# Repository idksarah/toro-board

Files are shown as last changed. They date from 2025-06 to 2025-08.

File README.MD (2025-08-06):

# toro-board
fully custom gasket mount 60% hot swappable alice keyboard using a raspberry pi pico. <br>
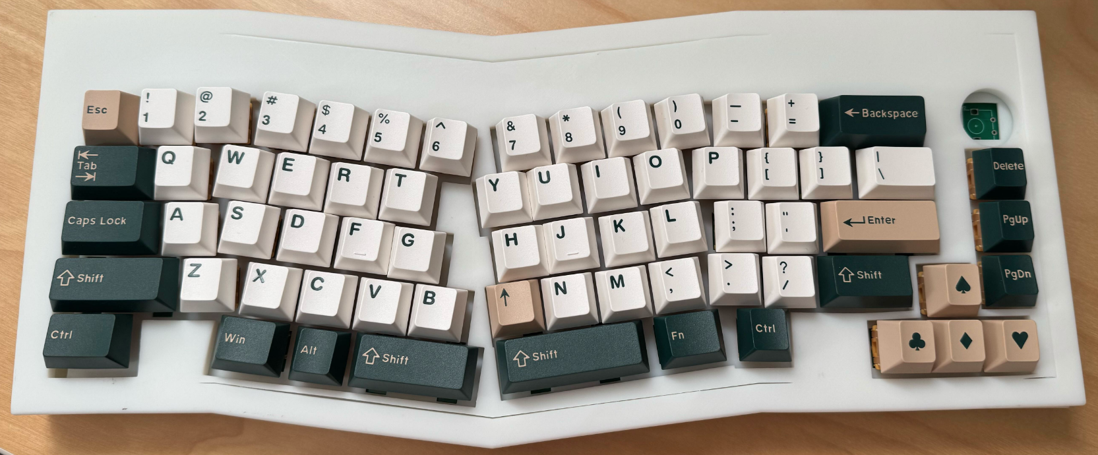
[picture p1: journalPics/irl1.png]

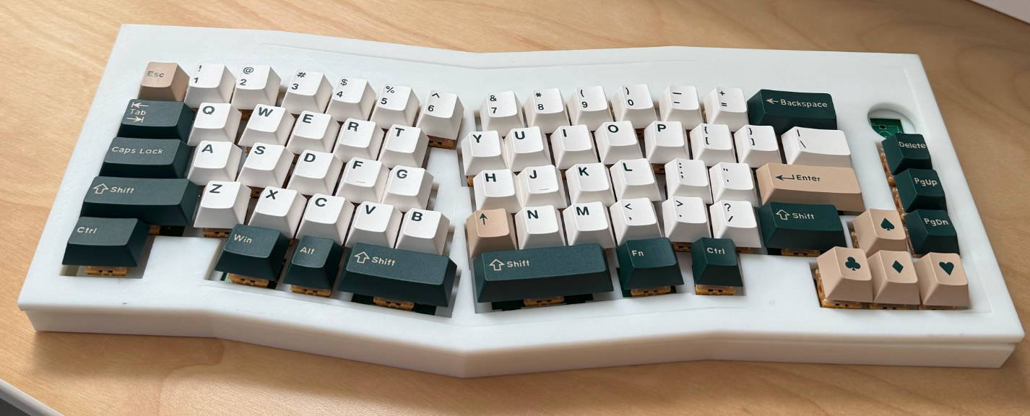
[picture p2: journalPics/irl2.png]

<br>
made this bc alice keyboards r cool but i've already spent too much on keyboards.
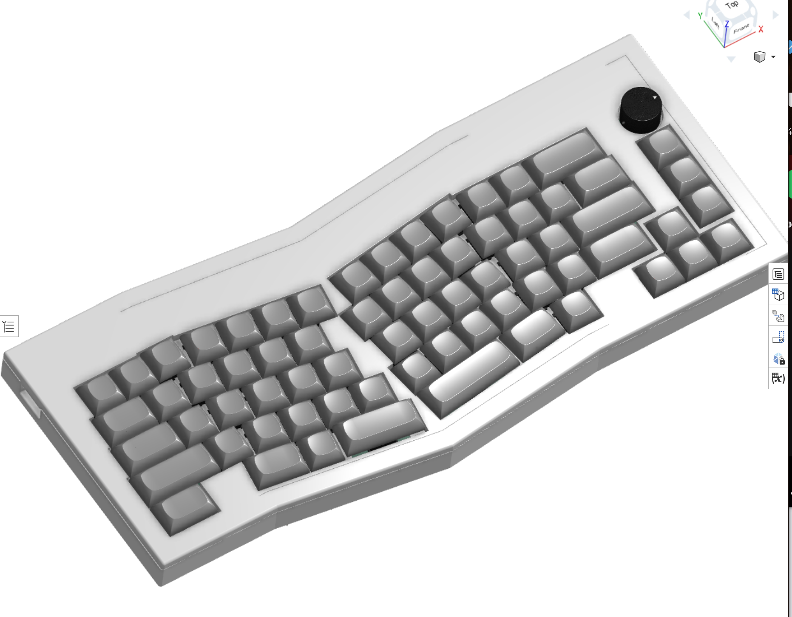
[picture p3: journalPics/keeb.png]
keeb

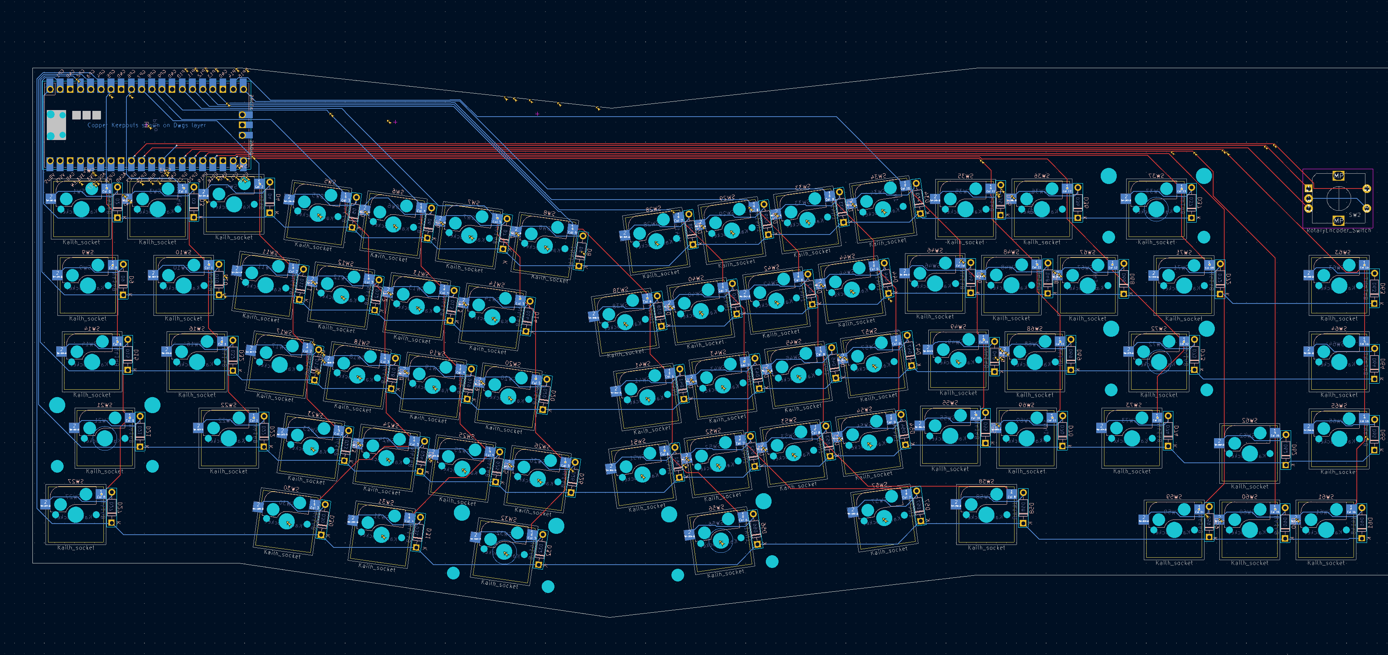
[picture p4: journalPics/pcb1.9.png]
pcb

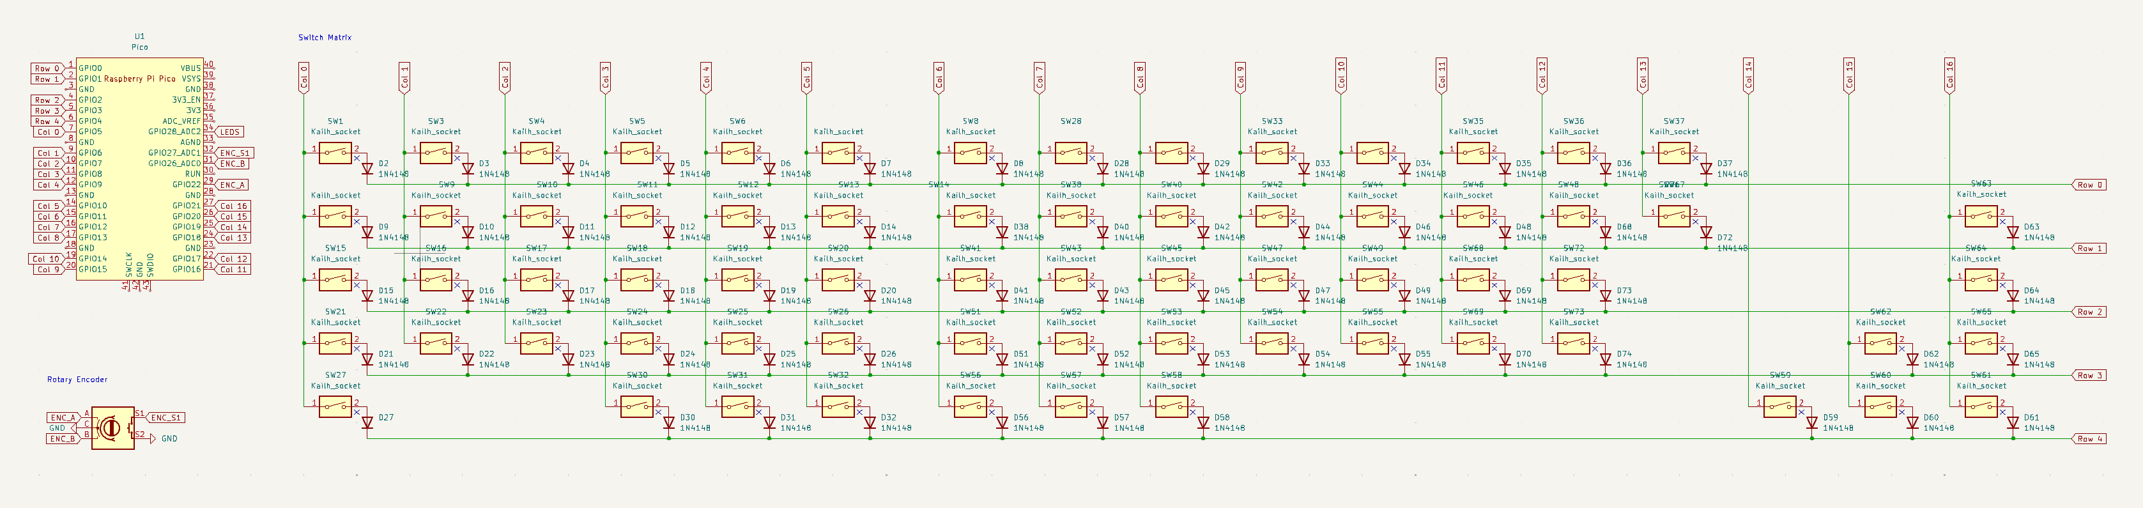
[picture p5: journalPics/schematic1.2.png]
idk


## firmware
qmk firmware

## bom

| item | quantity | price  | description | vendor | link |
|---|---|---|---|---|---|
| plate | 1 pc | 3.44 | 3d-printed acrylic plate | jlccnc | — |
| pcb | 5 pc | 21.60  | pcb | jlcpcb | — |
| case bottom | 1 pc | 28.34  | 3d-printed acrylic bottom case | jlccnc | — |
| case top | 1 pc | 9.35 | 3d-printed acrylic top case | jlccnc | — |
| [163 keys british racing green keyboard keycaps](https://www.aliexpress.us/item/3256807785511869.html) | 163 pc | 16.66  | keycaps | aliexpress | [link](https://www.aliexpress.us/item/3256807785511869.html) |
| [gateron ef curry switch 50g 5pin smd mx switch](https://www.aliexpress.us/item/3256805933064484.html) | 70 pc | 26.69 | ef curry switches | aliexpress | [link](https://www.aliexpress.us/item/3256805933064484.html) |
| [coiled keyboard cable type c to usb-a](https://www.aliexpress.us/item/3256808312113111.html) | 1 pc | 7.00 | usb c to usb a cable | aliexpress | [link](https://www.aliexpress.us/item/3256808312113111.html) |
| [70pcs kailh hot-swappable pcb socket hot plug](https://www.aliexpress.us/item/3256807039037559.html) | 70 pc | 3.73 | kailh hot swap sockets | aliexpress | [link](https://www.aliexpress.us/item/3256807039037559.html) |
| [15pcs gasket cotton strip](https://www.aliexpress.us/item/3256804985438216.html) | 15 pc | 3.74 | gasket for gasket mount  | aliexpress | [link](https://www.aliexpress.us/item/3256804985438216.html) |
| [switch puller tool](https://www.aliexpress.us/item/3256808571143767.html) | — | 3.92 | switch puller | aliexpress | [link](https://www.aliexpress.us/item/3256808571143767.html) |
| shipping (jlcpcb) | — | 20.00  | | jlcpcb | — |

---

### subtotals

- **jlcpcb total**: 21.60 (pcb) + 20.00 (shipping) → **$41.60**
- **aliexpress total**: 16.66 + 26.69 + 7.00 + 3.73 + 3.74 + 3.92 → **$61.74**
- **jlccnc total**: 3.44 + 28.34 + 9.35 → **$41.13**

---

### total: **$116.61**

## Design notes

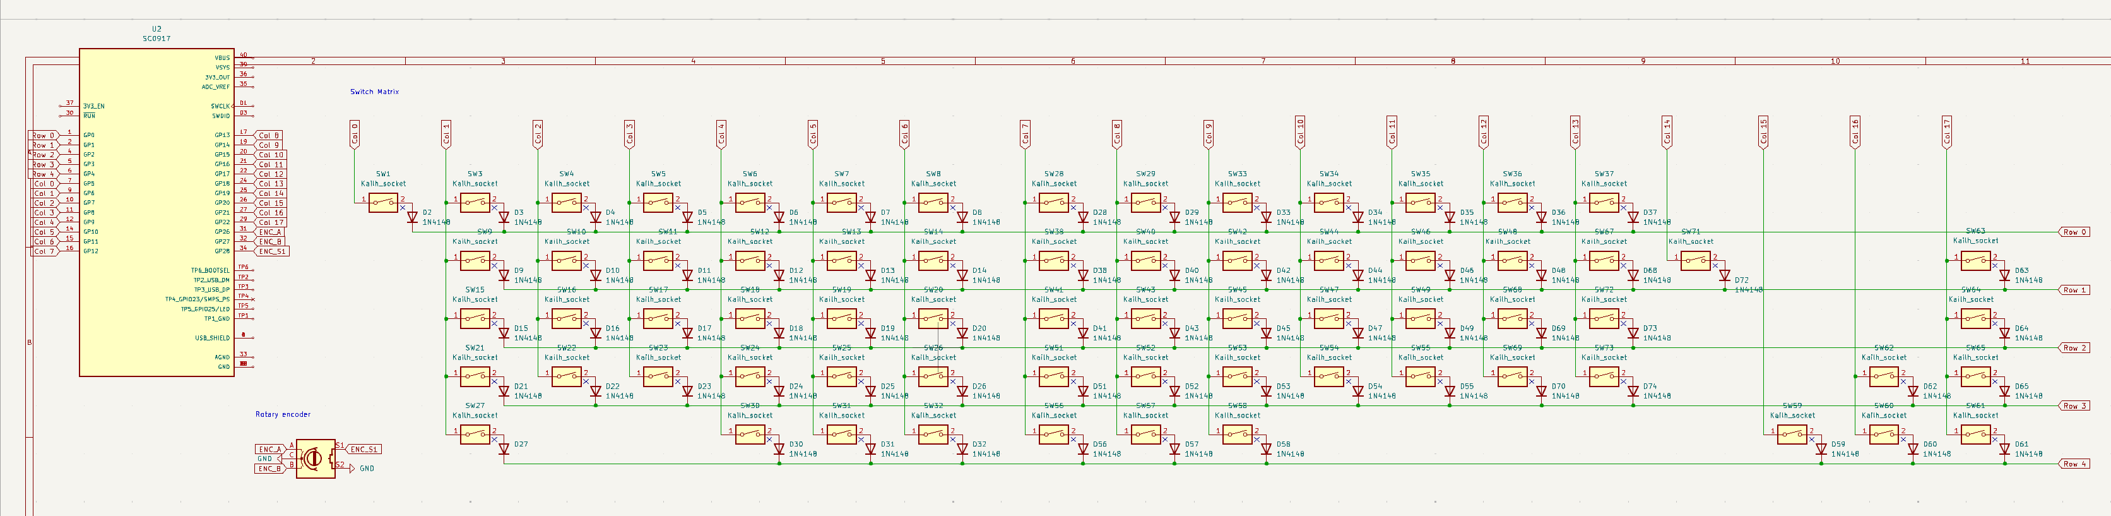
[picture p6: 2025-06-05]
journalPics/schematic1.png

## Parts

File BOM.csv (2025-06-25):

item | quantity | price | description | vendor | link
plate | 1 pc | 3.44 | 3d-printed acrylic plate | jlccnc | -
pcb | 5 pc | 21.60 | pcb | jlcpcb | -
case bottom | 1 pc | 28.34 | 3d-printed acrylic bottom case | jlccnc | -
case top | 1 pc | 9.35 | 3d-printed acrylic top case | jlccnc | -
163 keys british racing green keyboard keycaps | 163 pc | 16.66 | keycaps | aliexpress | https://www.aliexpress.us/item/3256807785511869.html
gateron ef curry switch 50g 5pin smd mx switch | 70 pc | 26.69 | ef curry switches | aliexpress | https://www.aliexpress.us/item/3256805933064484.html
coiled keyboard cable type c to usb-a | 1 pc | 7.00 | usb c to usb a cable | aliexpress | https://www.aliexpress.us/item/3256808312113111.html
70pcs kailh hot-swappable pcb socket hot plug | 70 pc | 3.73 | kailh hot swap sockets | aliexpress | https://www.aliexpress.us/item/3256807039037559.html
15pcs gasket cotton strip | 15 pc | 3.74 | gasket for gasket mount | aliexpress | https://www.aliexpress.us/item/3256804985438216.html
switch puller tool | - | 3.92 | switch puller | aliexpress | https://www.aliexpress.us/item/3256808571143767.html
shipping (jlcpcb) | - | 20.00 |  | jlcpcb | -

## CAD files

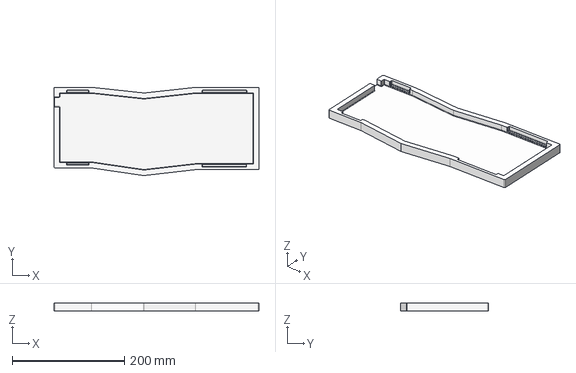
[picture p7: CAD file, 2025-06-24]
case-bottom/case-bottom - Part 1.step
365.3 x 157.1 x 15.0 mm

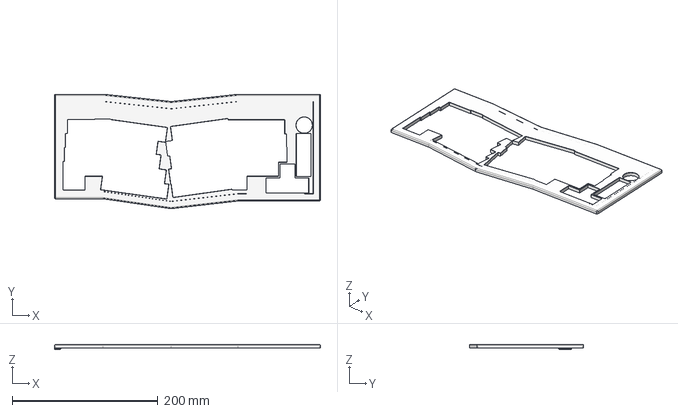
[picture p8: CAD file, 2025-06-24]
case-top/case-top - Part 1.step
365.3 x 157.1 x 7.00 mm

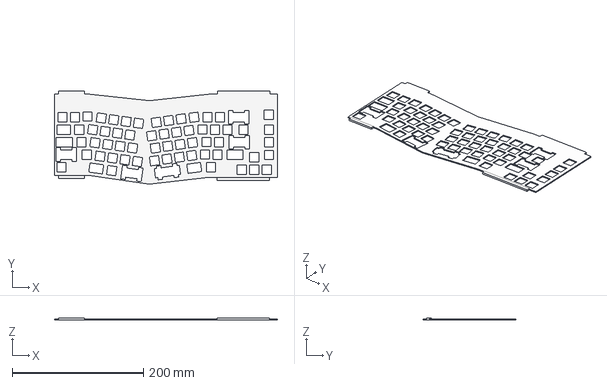
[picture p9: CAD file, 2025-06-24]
plate - Part 1/plate - Part 1 - Part 1.step
339.2 x 142.0 x 2.50 mm

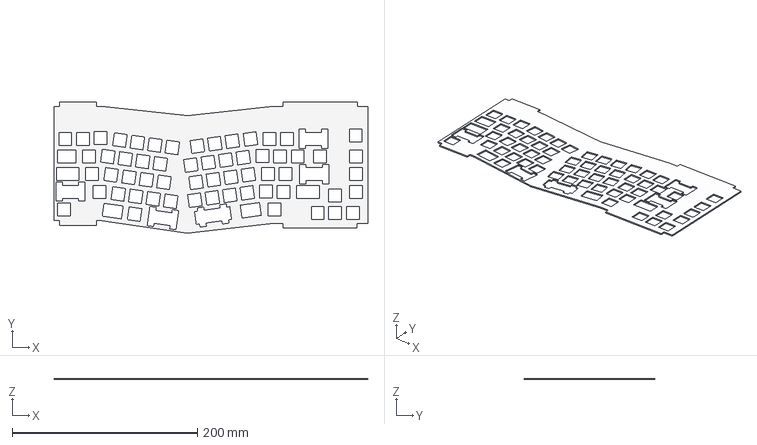
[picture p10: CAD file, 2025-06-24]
plate/plate - Part 1 - Part 1.step
339.2 x 142.0 x 1.50 mm

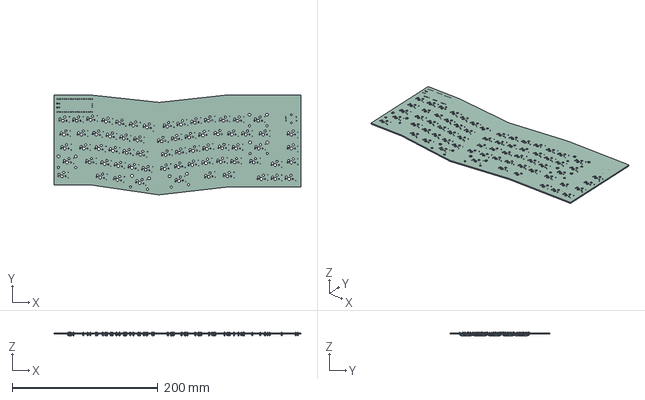
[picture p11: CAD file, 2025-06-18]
toro-pcb/toro-pcb.step
339.2 x 137.0 x 5.01 mm
D_DO-35_SOD27_P7.62mm_Horizontal x 68
toro-pcb_PCB

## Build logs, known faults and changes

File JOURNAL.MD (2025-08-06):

---
title: "toro-board"
author: "sarah ngai | @idksarah"
description: "keeb"
created_at: "2025-04-6"
---
# 29 hours
# 6/4/2025 (June 4 2025) <br>
# Entry #1<br>
## 4:25pm-5:51pm | 1.5 hours<br>
Researched parts<br>
-Kailh hot swap sockets <br>
-Xiao<br>
Researched layouts + mounting<br>
-Alice (ref https://www.reddit.com/r/MechanicalKeyboards/comments/xjspgk/first_full_build_feker_alice_80_the_ultimate/) ; still staggered<br>
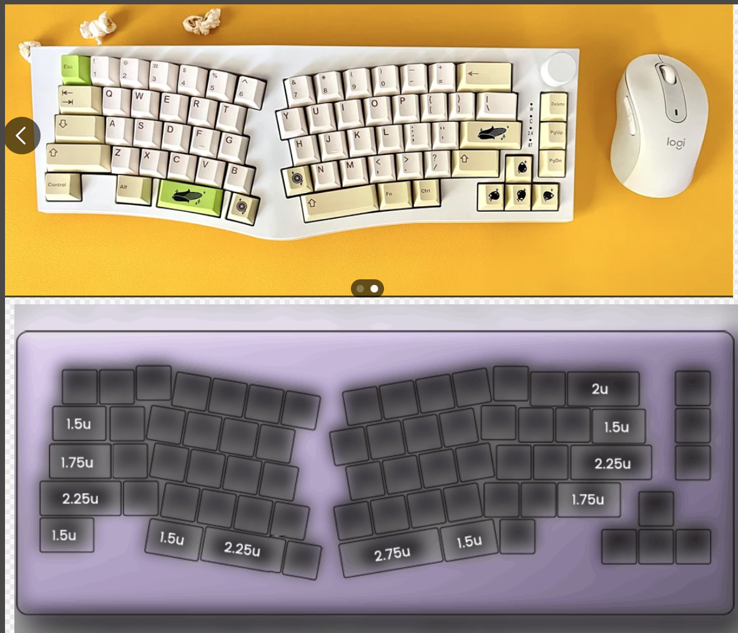
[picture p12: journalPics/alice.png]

-60% ofc :3
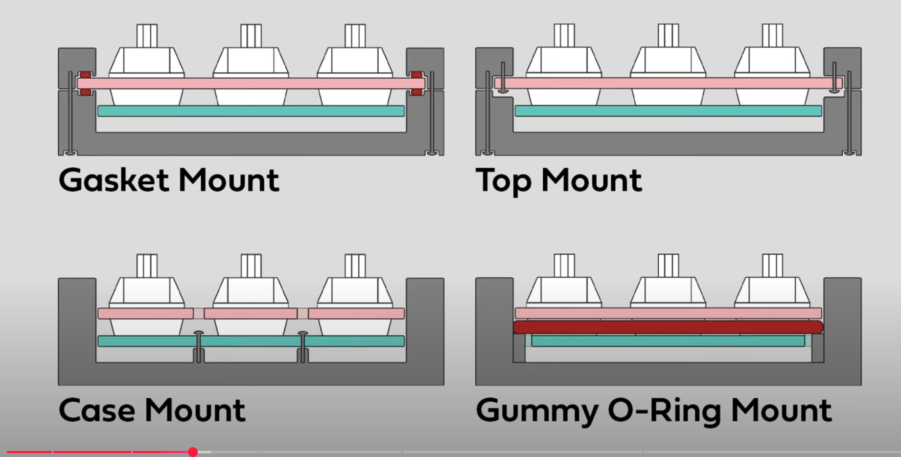
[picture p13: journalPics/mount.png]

Running with top mount i think
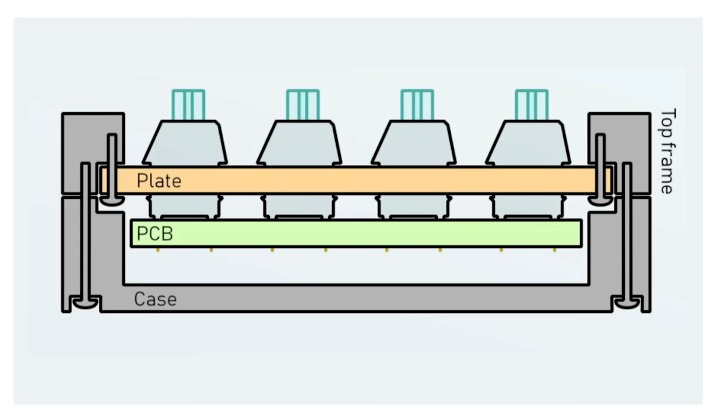
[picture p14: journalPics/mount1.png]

-Would love to CAD a PC/something with a screen so i can put a pic of toro inoue :3 dump in a light too
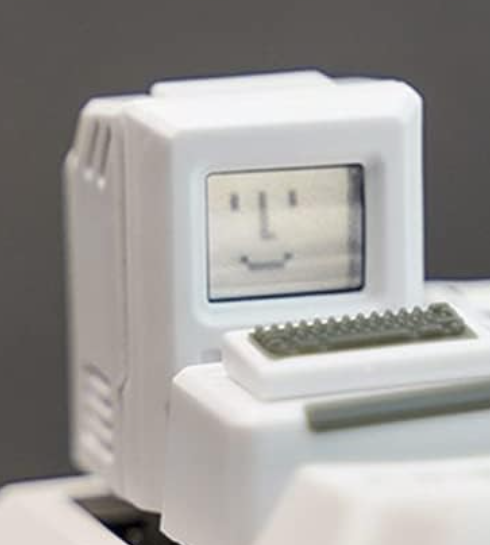
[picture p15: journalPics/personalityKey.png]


Read up on custom keeb designing guides :3 <br>
-https://github.com/ruiqimao/keyboard-pcb-guide <br>
-Will reference this https://github.com/Bemeier/bmek or this https://github.com/coarse/Cordillera for the PCB<br>

been stealing from pieboard for the design process 💀<br>
---
# 6/4/2025<br>
# Entry #2<br>
## 8:23pm-11:21pm | 3 hours <br>
imported necessary libraries (kailh, raspi pico), set up footprints for encoder specifically bc kicad didnt link the encoder symbol with its footprint? <br>
first draft of switch layout! linked the kailh socket with a random switch symbol but i have the footprint so its gwaenchana!<br>
schematic rn:[alt text](journalPics/schematic1.png) 

i was. talking to someone. i think my rasppi symbol might be wrong. #fried. will look into it later LMFAOO<br>
---
# 6/5/2025<br>
# Entry #3<br>
## 10:22am-11:44am | 1 hour <br>
added led string<br>
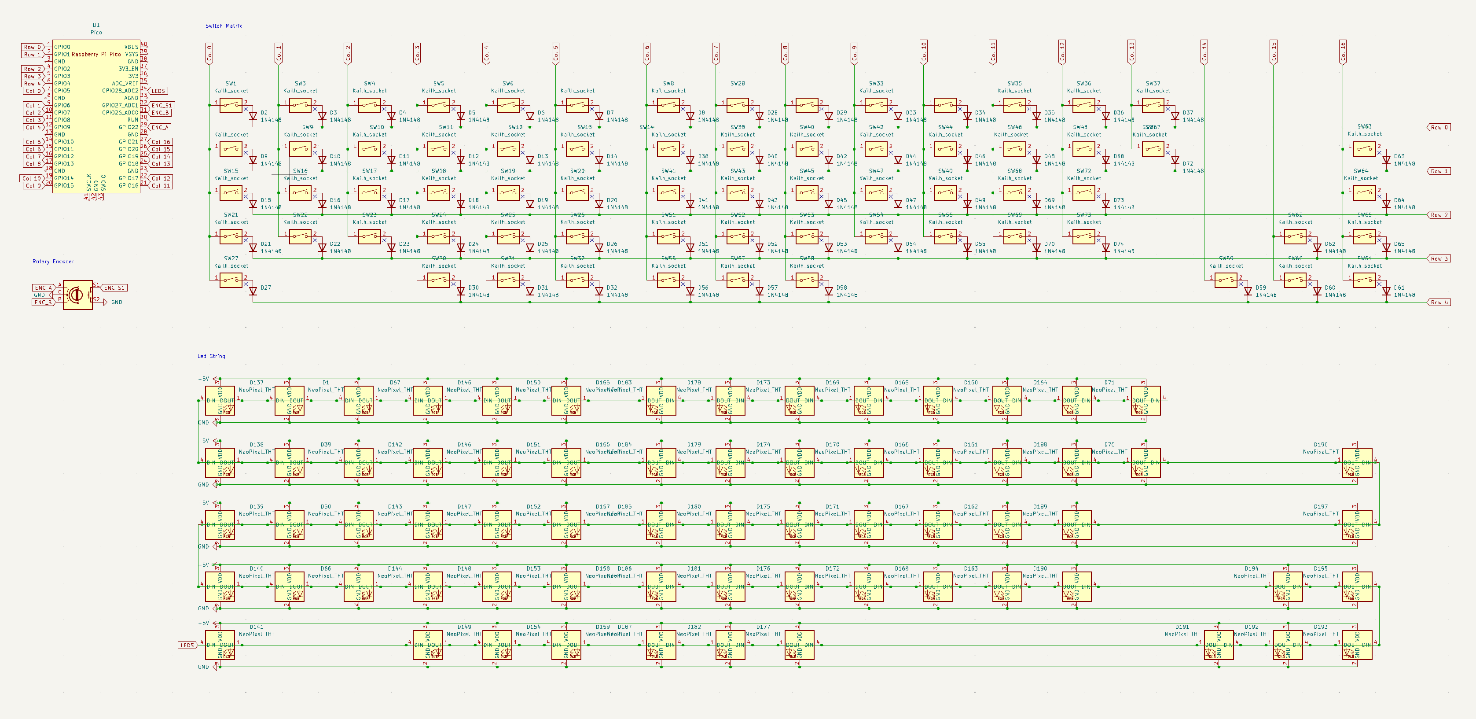
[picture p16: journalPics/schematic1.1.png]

---
# 6/5/2025<br>
# Entry # 4<br>
## 3:36pm-6:12 pm | 2.5 hours <br>
https://www.aliexpress.us/item/2251832437268792.html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 <br>

idontknowwhatimdoing. started the pcb
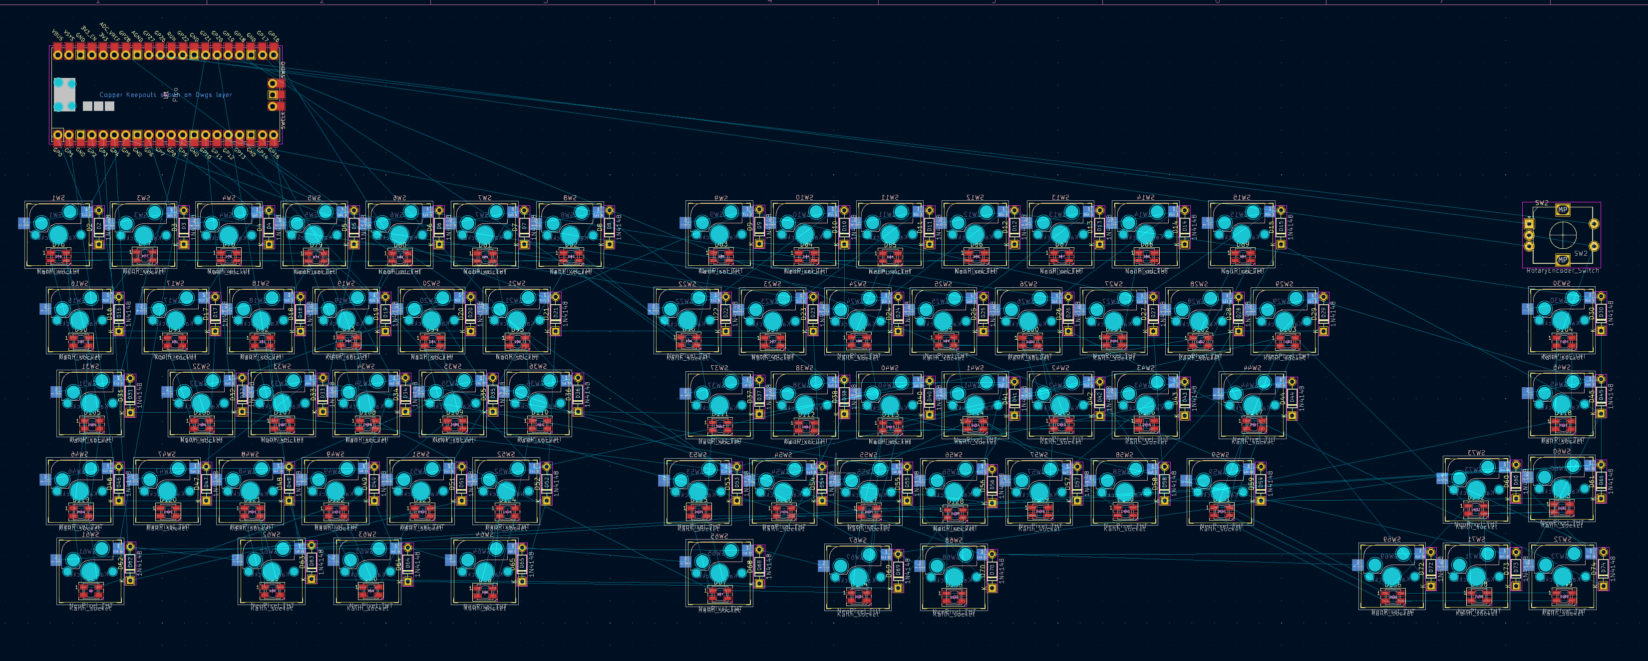
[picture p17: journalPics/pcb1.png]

---
# 6/5/2025<br>
# Entry #5<br>
## 9pm-12pm | 3 hours<br>
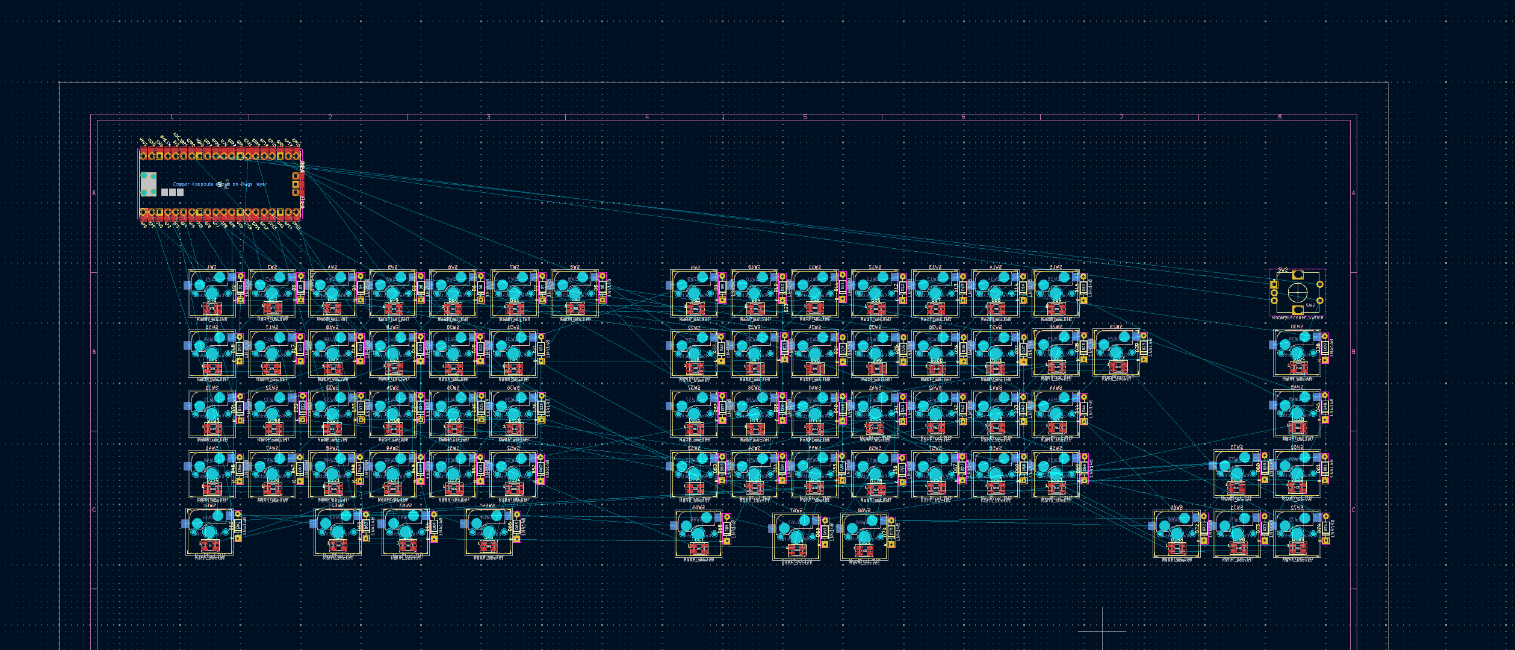
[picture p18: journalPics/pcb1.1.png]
Made the spacing between center holes 19.05 bc i was on the wrong grid before 💀
Swapping the windows and alt left keys. reg size keys<br>
gotta add stagger and review this bc i eyeballed all the support stuff 💀
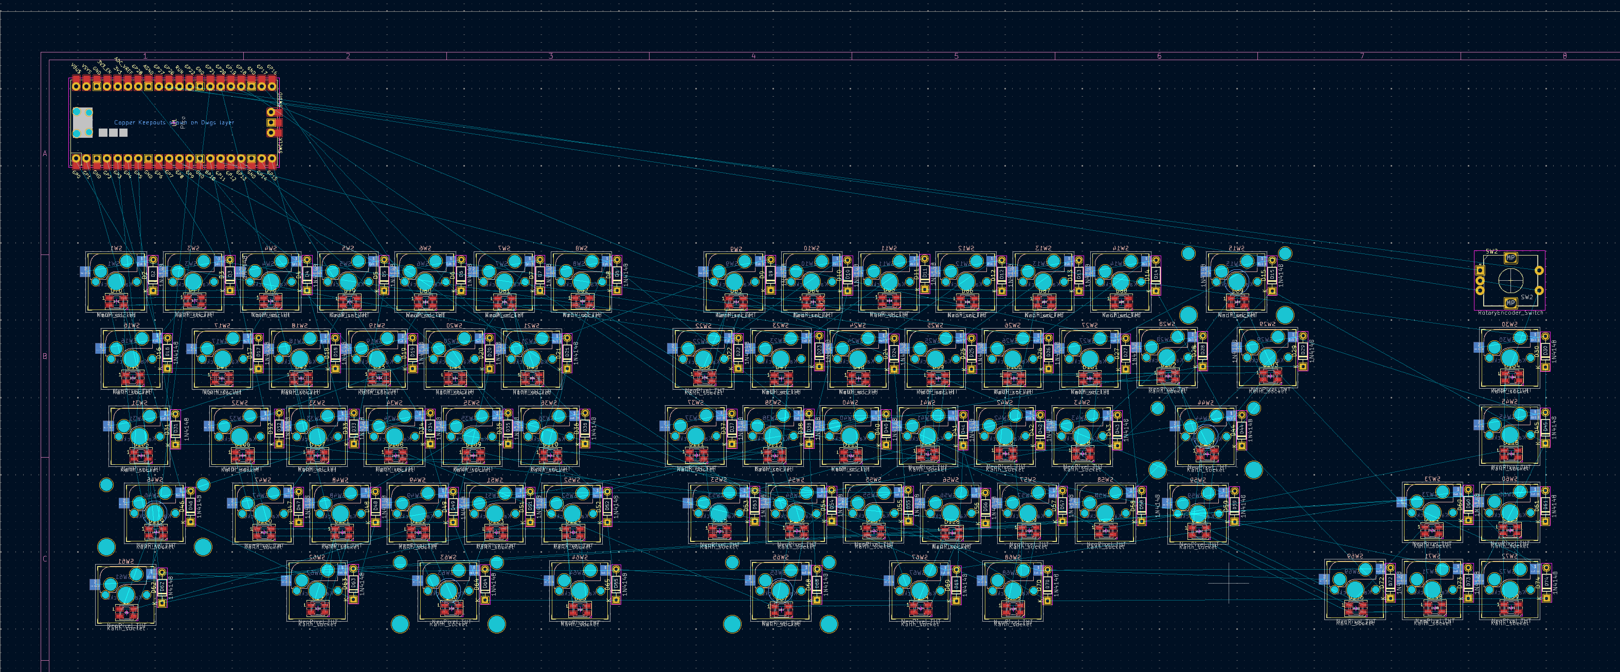
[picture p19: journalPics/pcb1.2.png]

---
# 6/6/2025<br>
# Entry #6<br>
## 12:27pm-1:49pm | 1.5 hours<br>

might put in a usb port? idk<br>
watched like. 10 vids on desigining a keeb. now understand why kerboards r $120. pls kil lme
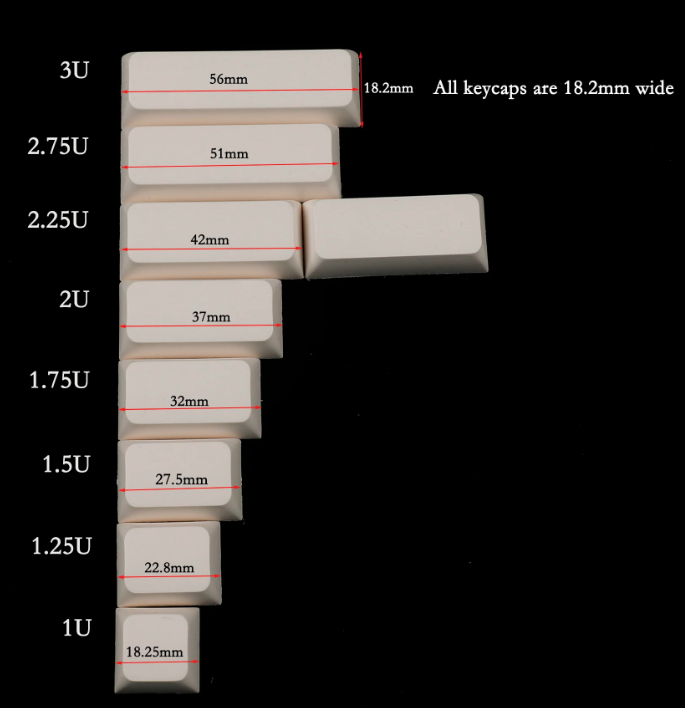
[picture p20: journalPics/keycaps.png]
<br>
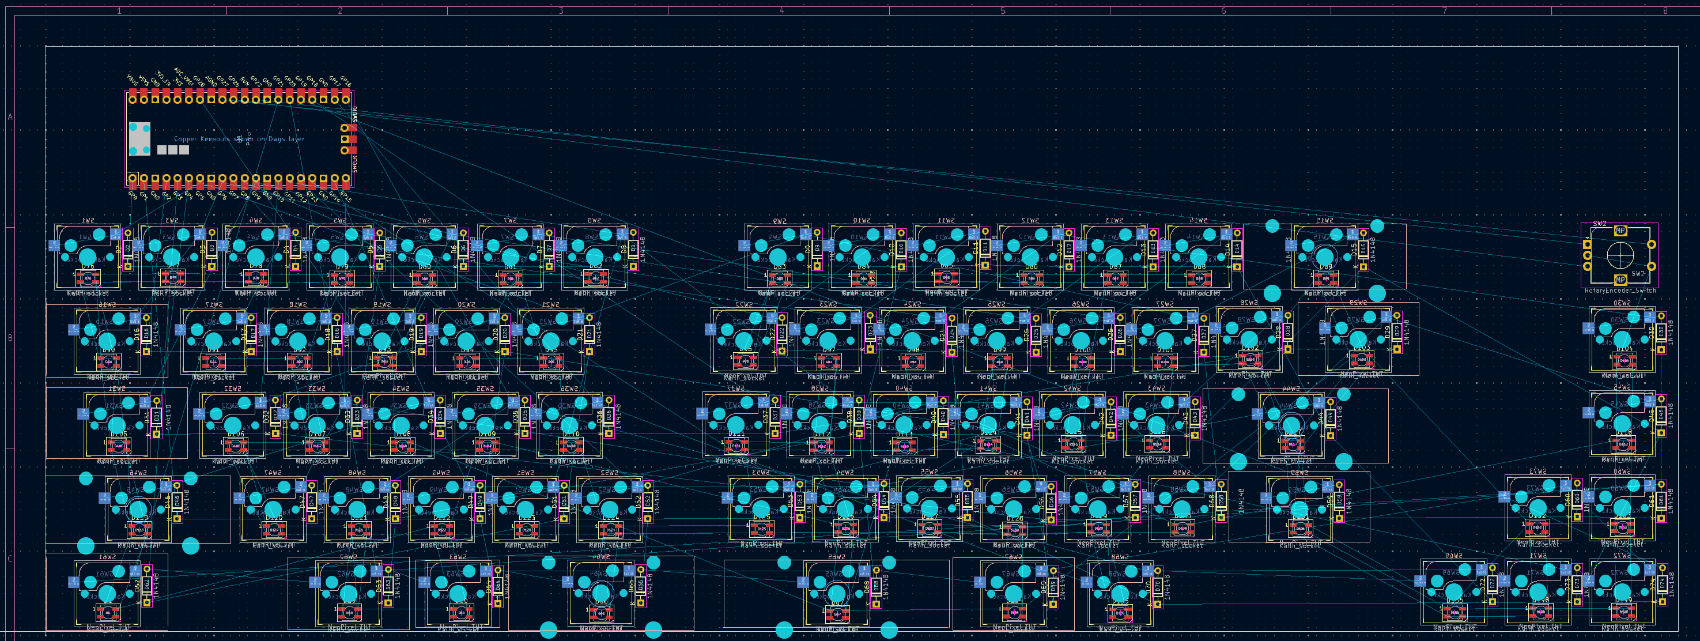
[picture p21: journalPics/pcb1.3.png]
no clue what im doing but i have to go study for the sat 
---
# 6/7/2025
# Entry #7
## 5:08pm-7:30 | 2.5 hours<br>
ok the flat layout is correct now i pray to god (like spacing and stuff) <br>
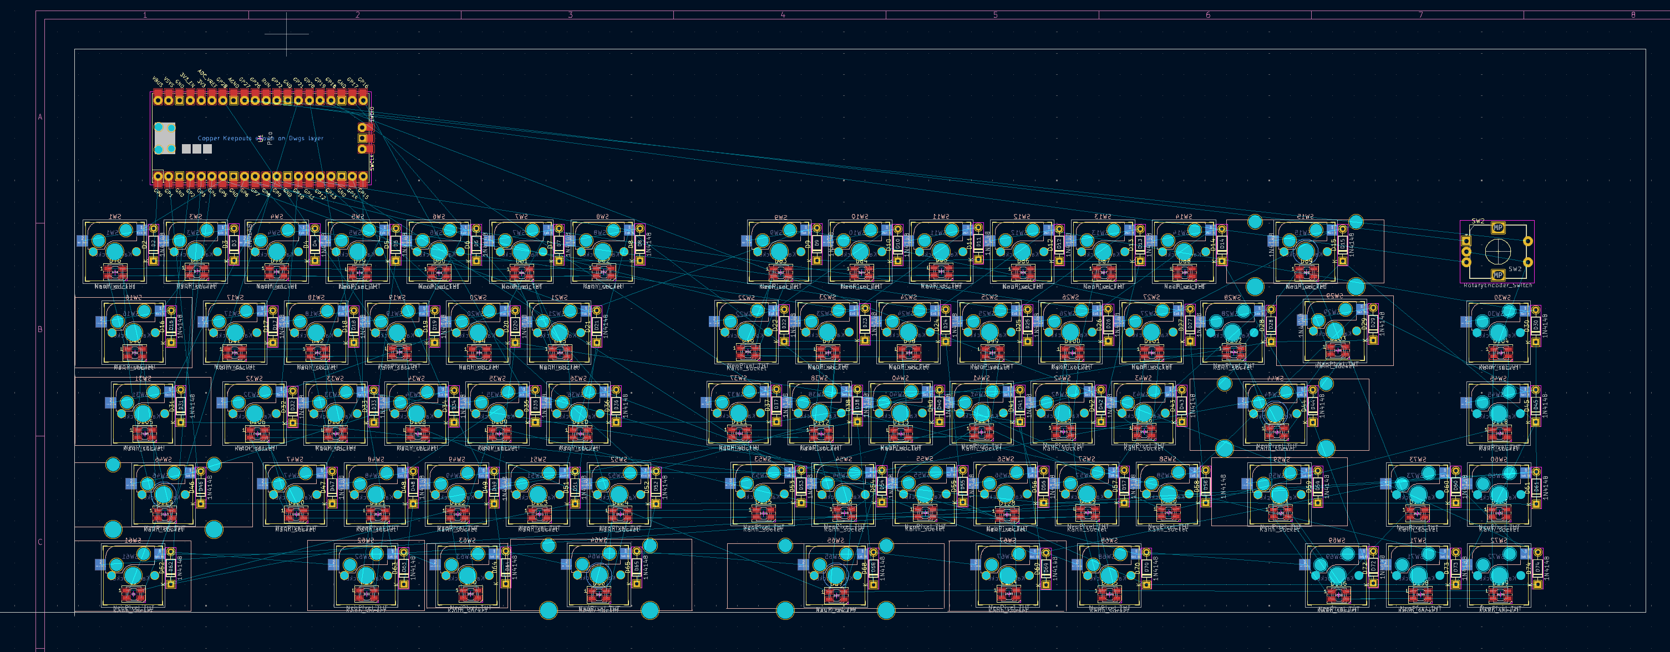
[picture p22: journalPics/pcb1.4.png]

time to rotate this shit and commit LMFAO <br>
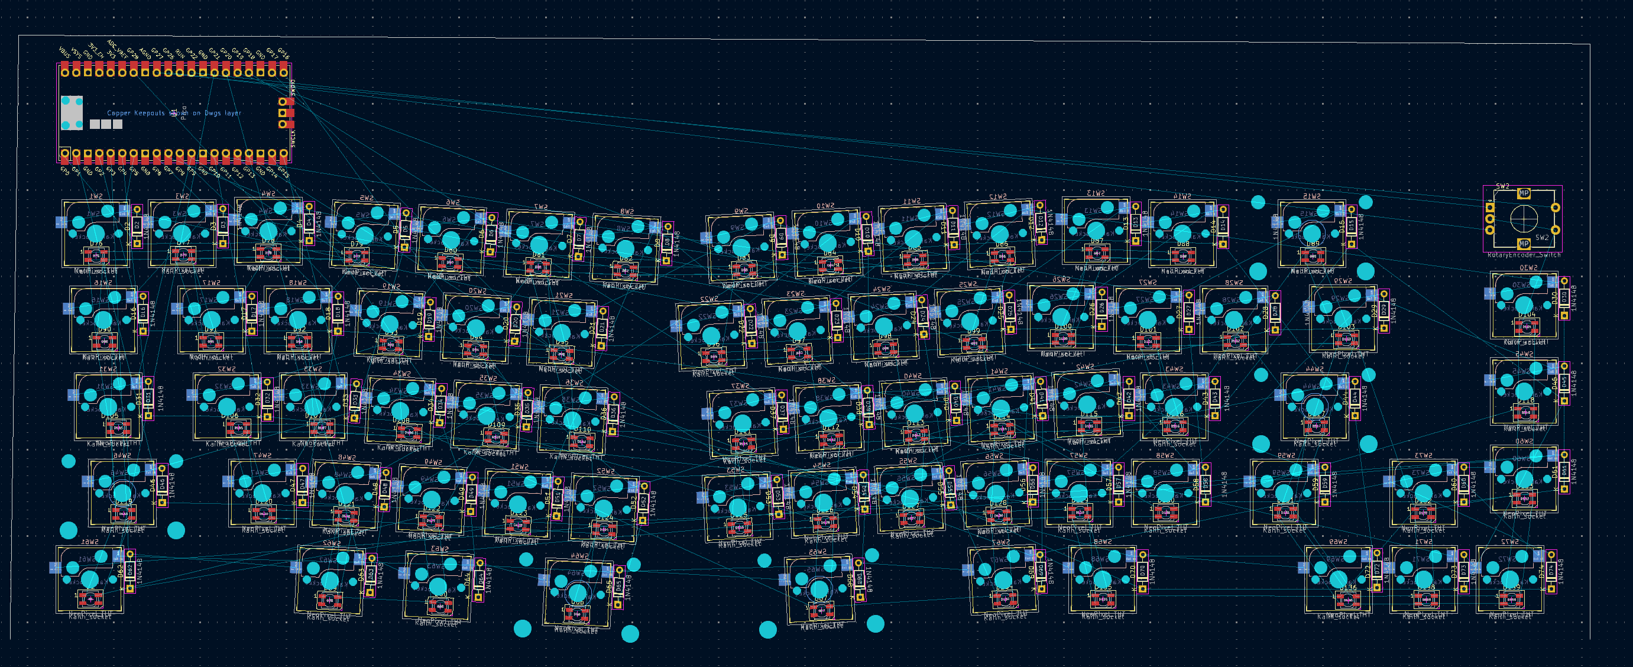
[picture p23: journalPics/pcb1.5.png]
was not that bad actually. 
i feel like a monkey given access to kicad<br>
referencing these keebs for looks: https://www.reddit.com/r/raspberry_pi/comments/x0rml6/pico_and_mechanical_keyboards_a_match_made_in/ and https://www.reddit.com/r/raspberry_pi/comments/mc9l6o/i_designed_a_raspberry_pi_pico_powered_mechanical/ <br>
# 6/8/2025 <br>
# Entry #8 <br>
## 2:29am-3:23am | 1 hour <br>
kittne ddaddys about to kill herself
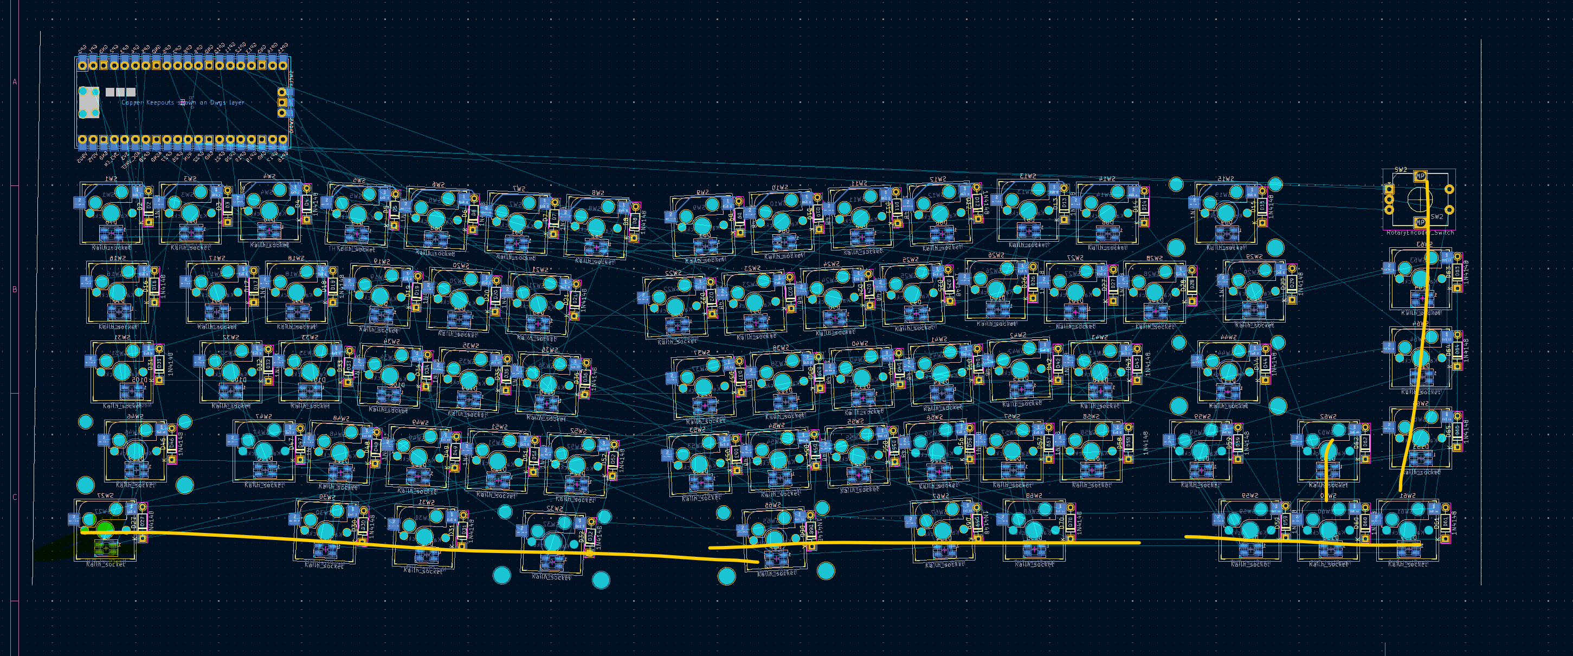
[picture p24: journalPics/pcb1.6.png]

basically i placed all my keys in the wrong place and theyre liike. in the perfect layout and i refuse to move them. so. im mnaullay renaming every switch and diode 💀💀 pls god kill me JK
im fried
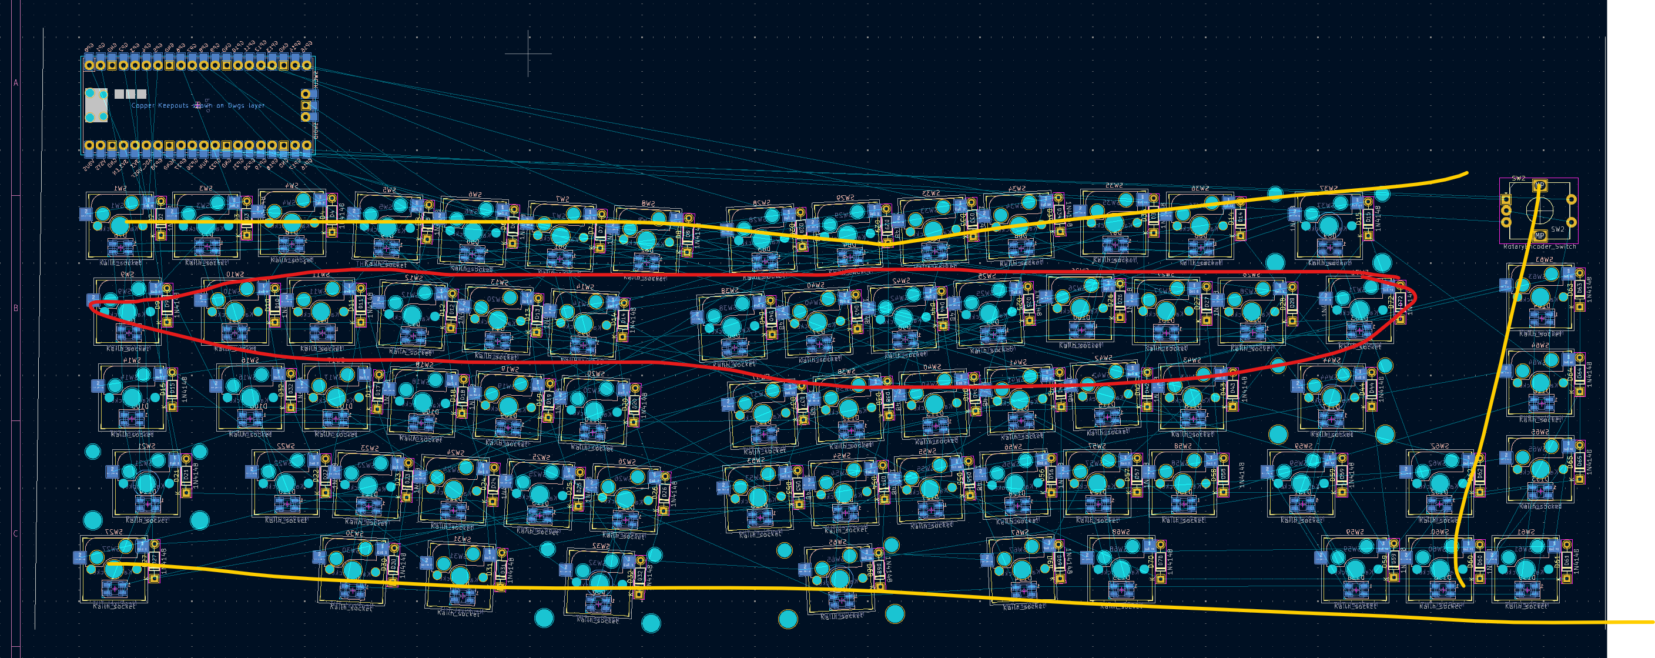
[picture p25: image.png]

# 6/10/2025 <br>
# Entry #9 <br>
## 8:36pm-11:20pm | 3 hours <br>
just got back from trip!!!!!! :D
i think it's wired???? i had to lowk rename everyl ike. switch. and diode. bc i had them in the wrong palce. wtv
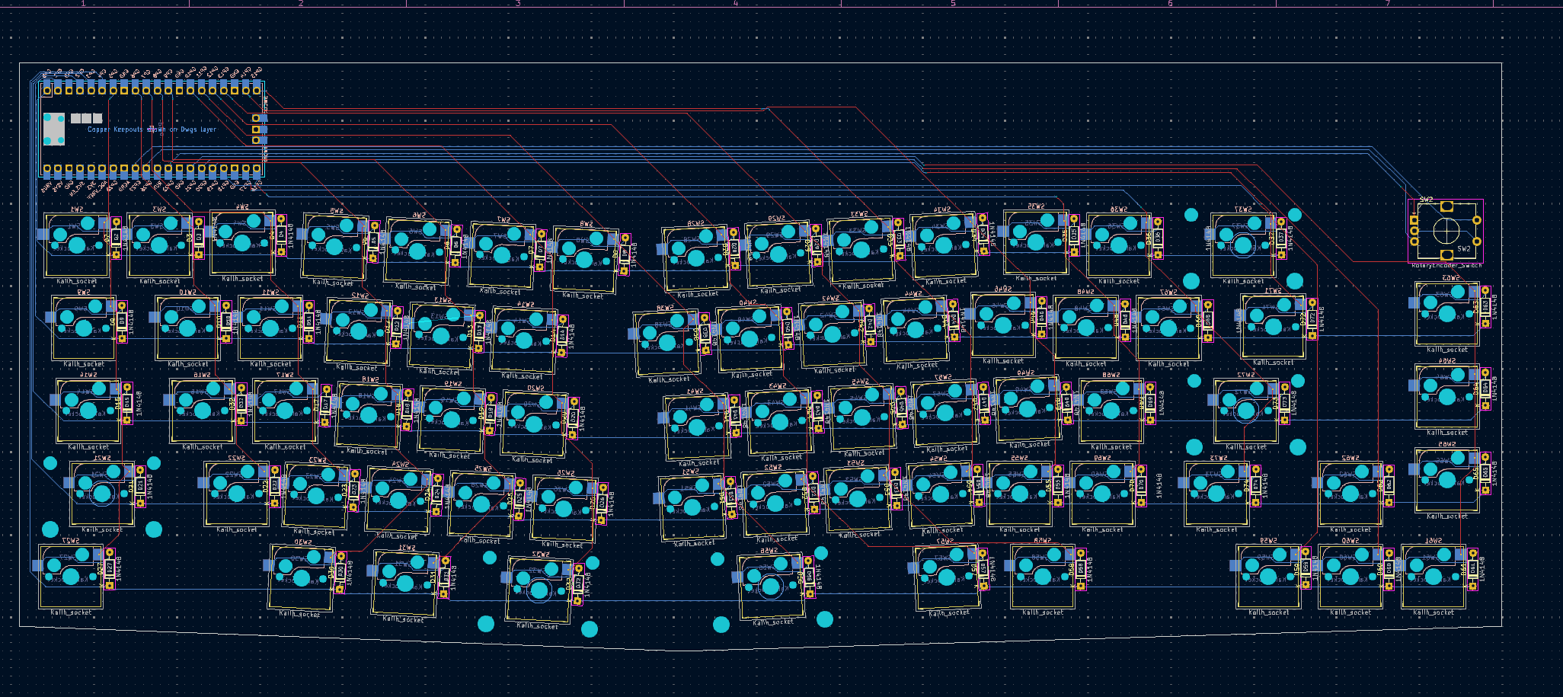
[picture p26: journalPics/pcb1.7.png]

ummm i hope this works bc i have to go make a mouse now. bye.
# 6/11/2025 <br>
# Entry #10 <br>
## 8:07 pm- <br>
we so back bitches!!!<br>
fixed some of the wiring. decided what i want the case to look like. prob gonna have to paint stuff on. time to get caddin! <br>
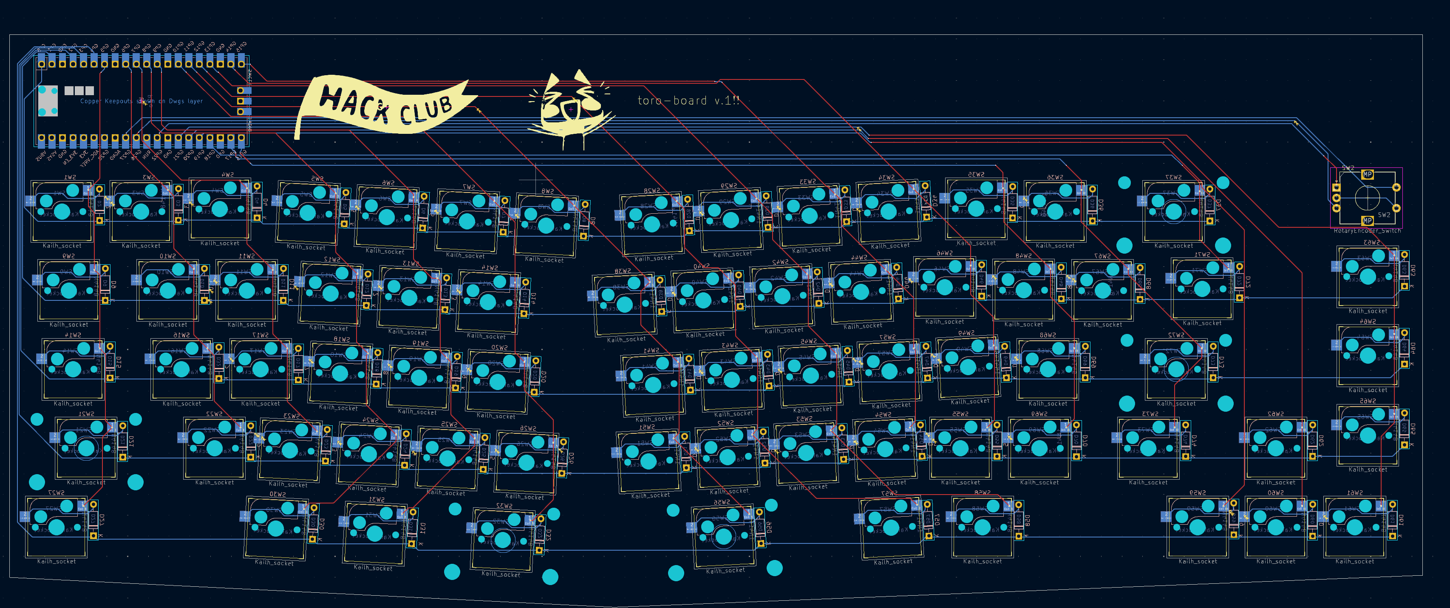
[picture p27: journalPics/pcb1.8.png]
silk screen stuff eheh
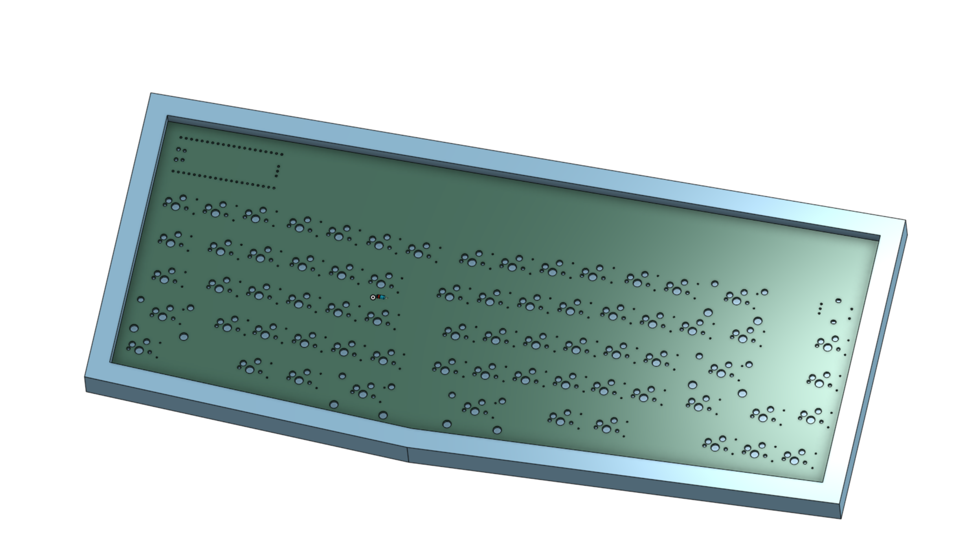
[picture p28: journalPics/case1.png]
type shit 
# 6/12/2025 <br>
# Entry #11 <br>
## 3 hours i swear
cadded the shyt in onshape. the keys should be rotated but im p sure theyre not just bc my switch model didnt have pins. im suuuuure it'll work (famous last words)
type shit 
# 6/15/2025 <br>
# Entry #11 <br>
# 2 hours ?
rotated the keys bc i want the rotation to be 8 degrees instead of 3 💀
# 6/16/2025<br>
# Entry #12
fixed the gaps between keys/rows in onshape + kicad. started on the plate. threw all the keycaps on the switches too. ss is without the caps bc thats how i was making the plate and im too lazy to unhide them. my computer is about to explode 💀
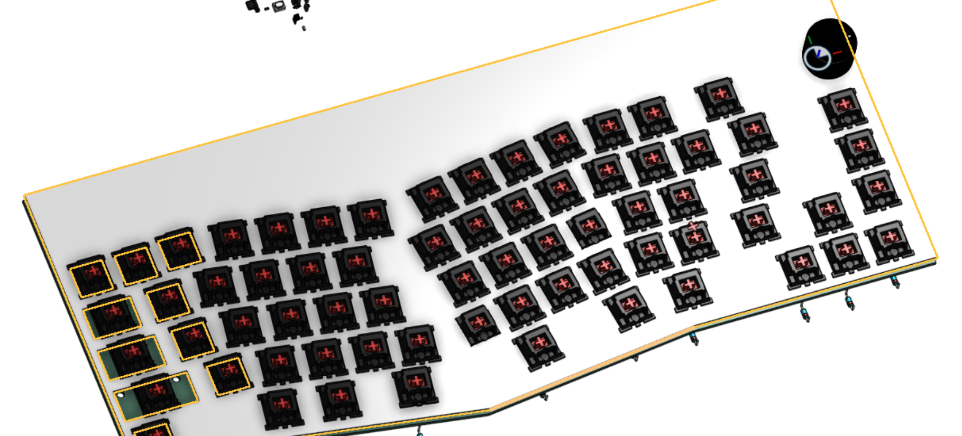
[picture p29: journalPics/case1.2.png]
 
# 6/17/25
rewired pcb so my raspi can be like. .2 a mm closer to the keys 💀 (actually bc of the key rotation)

# 7/28
1 hours<br>
soldered that shit! threw all the keys into the plate! and threw the keycaps on bc im overzealous like that<br>
also ordered diodes, rotary encoder, and key stabilizers bc i apparently forgot 💀<br>
# 8/1 <br>
2 hours<br>
soldered diodes. key stabilizers arrived. waiting on encoder <br>
# 8/2 <br>
2 hour<br>
rewriting and testing kmk firmware bc u can't run qmk on a pico 💀. switches don't seem to work so just testing pcb with a ppclip.
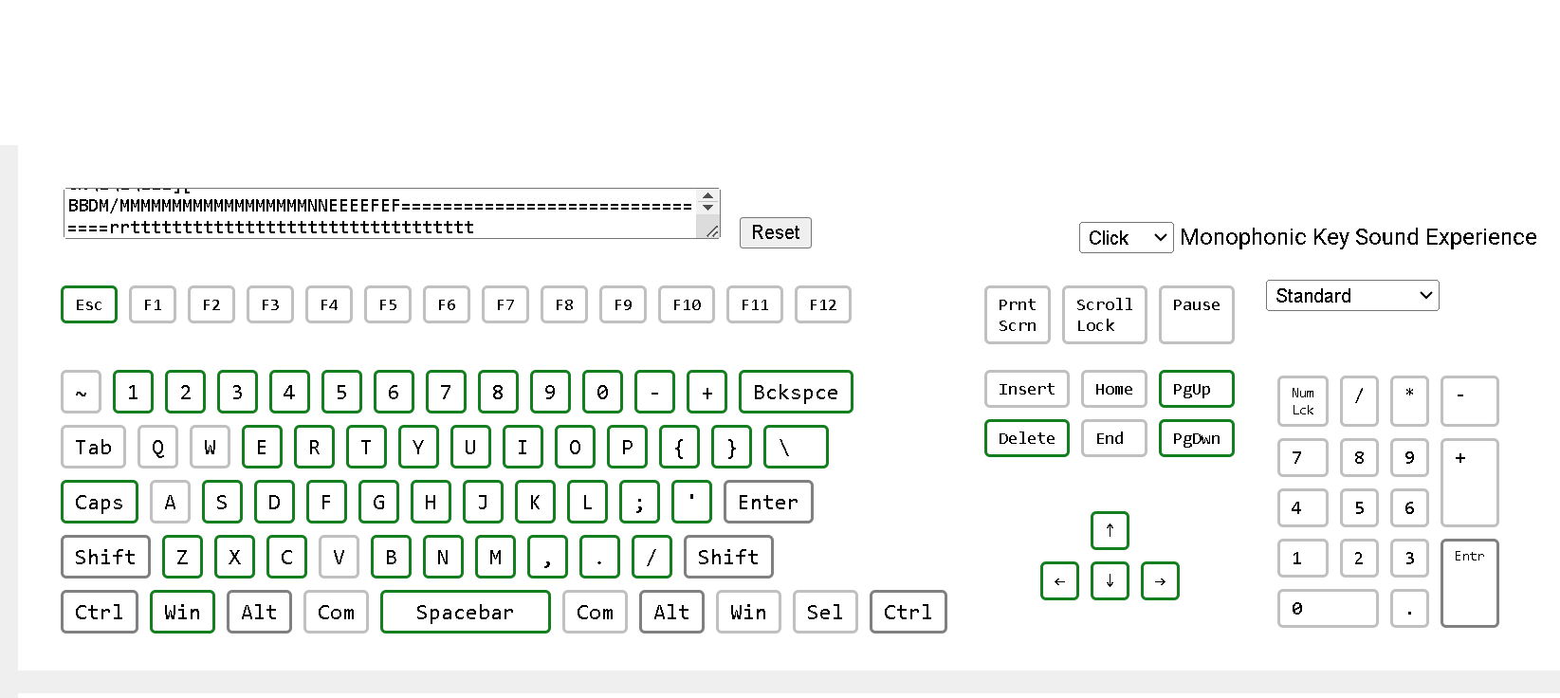
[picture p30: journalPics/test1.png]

# 8/6 <br>
1 hour<br>
assembly


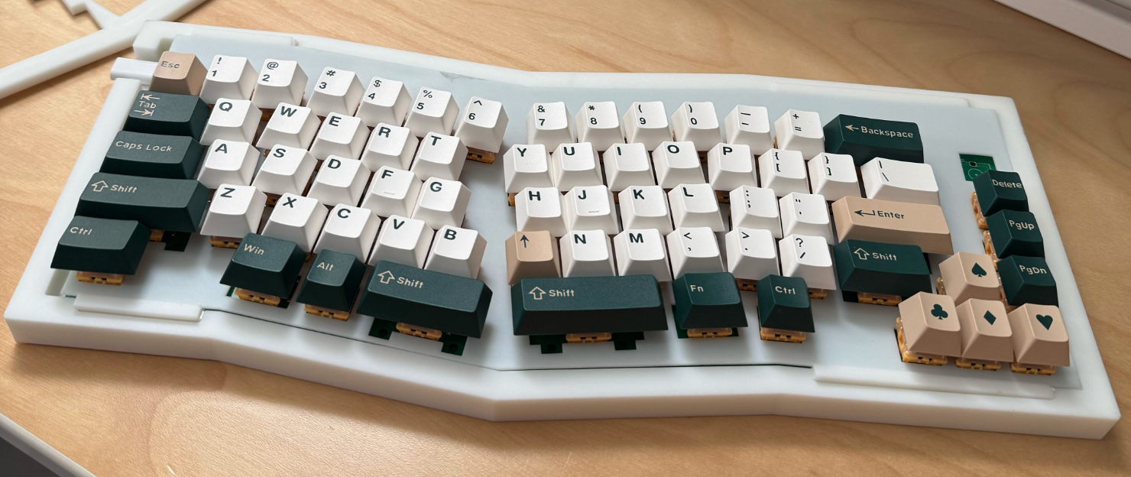
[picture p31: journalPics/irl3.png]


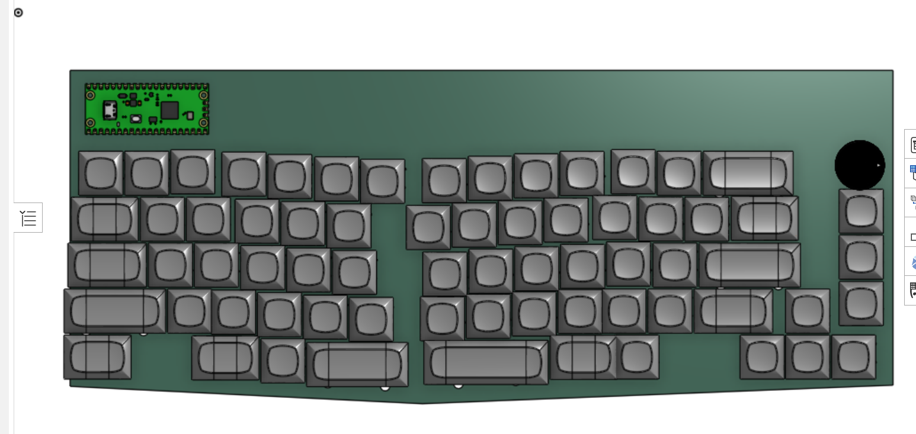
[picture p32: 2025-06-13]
journalPics/case1.1.png

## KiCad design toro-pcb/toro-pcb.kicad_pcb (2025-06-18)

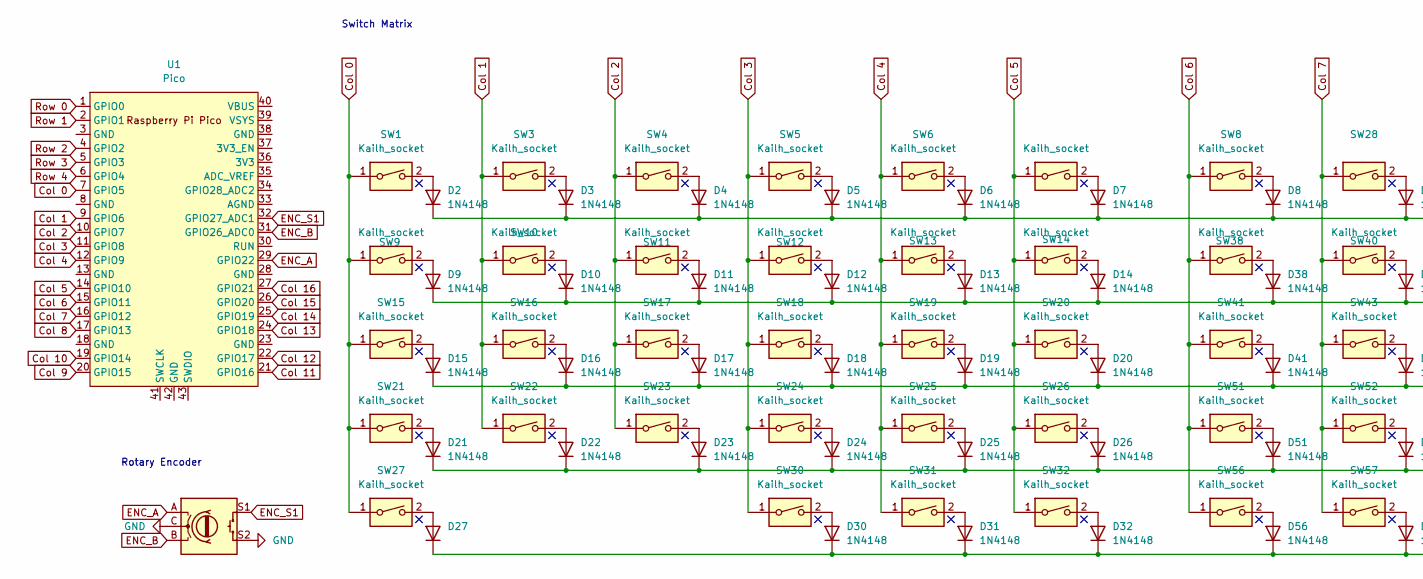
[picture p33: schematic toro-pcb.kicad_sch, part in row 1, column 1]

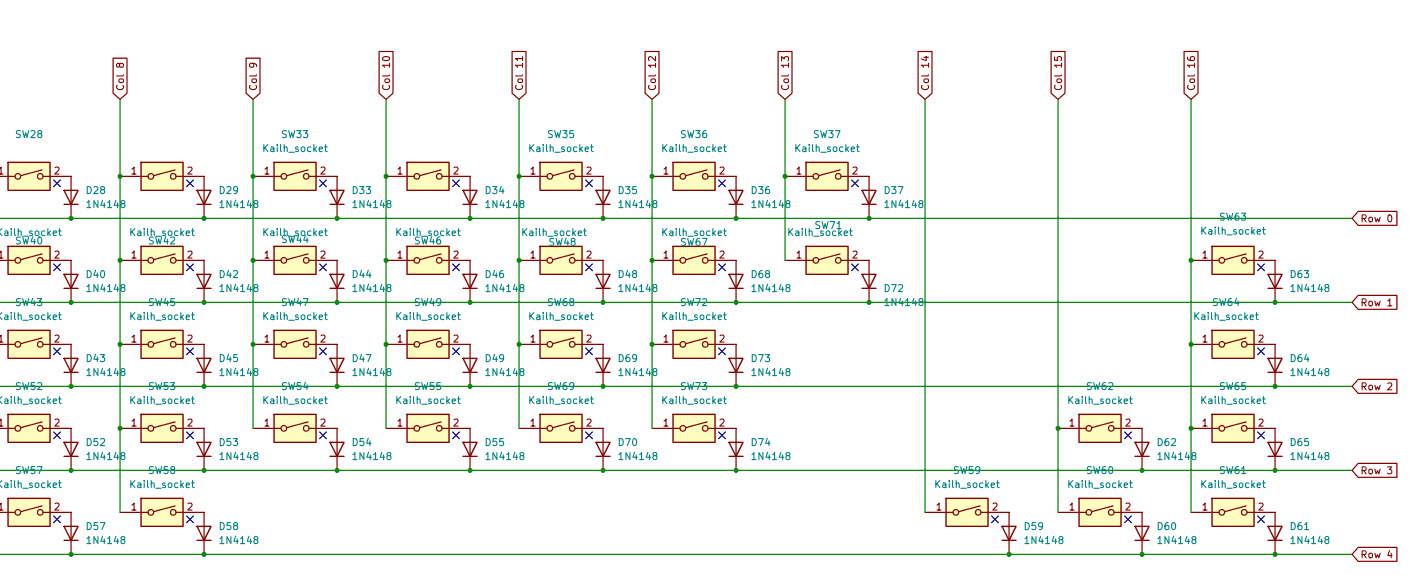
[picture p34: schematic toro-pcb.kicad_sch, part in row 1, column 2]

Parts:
D2, D3, D4, D5, D6, D7, D8, D9, D10, D11, D12, D13, D14, D15, D16, D17, D18, D19, D20, D21, D22, D23, D24, D25, D26, D27, D28, D29, D30, D31, D32, D33, D34, D35, D36, D37, D38, D40, D41, D42, D43, D44, D45, D46, D47, D48, D49, D51, D52, D53, D54, D55, D56, D57, D58, D59, D60, D61, D62, D63, D64, D65, D68, D69, D70, D72, D73, D74: 1N4148; D_DO-35_SOD27_P7.62mm_Horizontal
SW1, SW3, SW4, SW5, SW6, SW7, SW8, SW9, SW10, SW11, SW12, SW13, SW14, SW15, SW16, SW17, SW18, SW19, SW20, SW21, SW22, SW23, SW24, SW25, SW26, SW27, SW28, SW29, SW30, SW31, SW32, SW33, SW34, SW35, SW36, SW37, SW38, SW40, SW41, SW42, SW43, SW44, SW45, SW46, SW47, SW48, SW49, SW51, SW52, SW53, SW54, SW55, SW56, SW57, SW58, SW59, SW60, SW61, SW62, SW63, SW64, SW65, SW67, SW68, SW69, SW71, SW72, SW73: Kailh_socket; Kailh_socket_MX
SW2: RotaryEncoder_Switch; RotaryEncoder_Alps_EC12E-Switch_Vertical_H20mm
U1: Pico; RPi_Pico_SMD_TH

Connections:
Col 1: SW3.1, SW10.1, SW16.1, SW22.1, U1.9 (GPIO6)
Col 2: SW4.1, SW11.1, SW17.1, SW23.1, U1.10 (GPIO7)
Col 3: SW5.1, SW12.1, SW18.1, SW24.1, SW30.1, U1.11 (GPIO8)
Col 4: SW6.1, SW13.1, SW19.1, SW25.1, SW31.1, U1.12 (GPIO9)
Col 6: SW8.1, SW38.1, SW41.1, SW51.1, SW56.1, U1.15 (GPIO11)
Col 7: SW28.1, SW40.1, SW43.1, SW52.1, SW57.1, U1.16 (GPIO12)
Col 8: SW29.1, SW42.1, SW45.1, SW53.1, SW58.1, U1.17 (GPIO13)
Col 9: SW33.1, SW44.1, SW47.1, SW54.1, U1.20 (GPIO15); also elsewhere on the board
Col 10: SW34.1, SW46.1, SW49.1, SW55.1, U1.19 (GPIO14)
Col 11: SW35.1, SW48.1, SW68.1, SW69.1, U1.21 (GPIO16)
Col 12: SW36.1, SW67.1, SW72.1, SW73.1, U1.22 (GPIO17)
Col 13: SW37.1, SW71.1, U1.24 (GPIO18)
Col 14: SW59.1, U1.25 (GPIO19)
Col 15: SW60.1, SW62.1, U1.26 (GPIO20)
Col 16: SW61.1, SW63.1, SW64.1, SW65.1, U1.27 (GPIO21)
ENC_A: SW2.A, U1.29 (GPIO22)
ENC_B: SW2.B, U1.31 (GPIO26_ADC0)
ENC_S1: SW2.S1, U1.32 (GPIO27_ADC1)
GND: SW2.C, SW2.S2
LEDS: U1.34 (GPIO28_ADC2)
unnamed: D2.2 (A), SW1.2
unnamed: D3.2 (A), SW3.2
unnamed: D4.2 (A), SW4.2
unnamed: D5.2 (A), SW5.2
unnamed: D6.2 (A), SW6.2
unnamed: D7.2 (A), SW7.2
unnamed: D8.2 (A), SW8.2
unnamed: D9.2 (A), SW9.2
unnamed: D10.2 (A), SW10.2
unnamed: D11.2 (A), SW11.2
unnamed: D12.2 (A), SW12.2
unnamed: D13.2 (A), SW13.2
unnamed: D17.2 (A), SW17.2
unnamed: D18.2 (A), SW18.2
unnamed: D19.2 (A), SW19.2
unnamed: D20.2 (A), SW20.2
unnamed: D21.2 (A), SW21.2
unnamed: D22.2 (A), SW22.2
unnamed: D23.2 (A), SW23.2
unnamed: D24.2 (A), SW24.2
unnamed: D25.2 (A), SW25.2
unnamed: D26.2 (A), SW26.2
unnamed: D27.2 (A), SW27.2
unnamed: D28.2 (A), SW28.2
unnamed: D29.2 (A), SW29.2
unnamed: D30.2 (A), SW30.2
unnamed: D31.2 (A), SW31.2
unnamed: D33.2 (A), SW33.2
unnamed: D34.2 (A), SW34.2
unnamed: D35.2 (A), SW35.2
unnamed: D36.2 (A), SW36.2
unnamed: D37.2 (A), SW37.2
unnamed: D38.2 (A), SW38.2
unnamed: D40.2 (A), SW40.2
unnamed: D41.2 (A), SW41.2
unnamed: D42.2 (A), SW42.2
unnamed: D43.2 (A), SW43.2
unnamed: D44.2 (A), SW44.2
unnamed: D45.2 (A), SW45.2
unnamed: D46.2 (A), SW46.2
unnamed 60: D47.2 (A), SW47.2; also elsewhere on the board
unnamed: D48.2 (A), SW48.2
unnamed: D49.2 (A), SW49.2
unnamed: D51.2 (A), SW51.2
unnamed: D52.2 (A), SW52.2
unnamed: D53.2 (A), SW53.2
unnamed: D54.2 (A), SW54.2
unnamed: D55.2 (A), SW55.2
unnamed: D56.2 (A), SW56.2
unnamed: D57.2 (A), SW57.2
unnamed: D58.2 (A), SW58.2
unnamed: D59.2 (A), SW59.2
unnamed: D60.2 (A), SW60.2
unnamed: D61.2 (A), SW61.2
unnamed: D62.2 (A), SW62.2
unnamed: D63.2 (A), SW63.2
unnamed: D64.2 (A), SW64.2
unnamed: D65.2 (A), SW65.2
unnamed: D68.2 (A), SW67.2
unnamed: D69.2 (A), SW68.2
unnamed: D70.2 (A), SW69.2
unnamed: D72.2 (A), SW71.2
unnamed: D73.2 (A), SW72.2
unnamed: D74.2 (A), SW73.2
Row 0: D2.1 (K), D3.1 (K), D4.1 (K), D5.1 (K), D6.1 (K), D7.1 (K), D8.1 (K), D28.1 (K), D29.1 (K), D33.1 (K), D34.1 (K), D35.1 (K), D36.1 (K), D37.1 (K), U1.1 (GPIO0)
Row 1: D9.1 (K), D10.1 (K), D11.1 (K), D12.1 (K), D13.1 (K), D14.1 (K), D38.1 (K), D40.1 (K), D42.1 (K), D44.1 (K), D46.1 (K), D48.1 (K), D63.1 (K), D68.1 (K), D72.1 (K), U1.2 (GPIO1)
Row 3: D21.1 (K), D22.1 (K), D23.1 (K), D24.1 (K), D25.1 (K), D26.1 (K), D51.1 (K), D52.1 (K), D53.1 (K), D54.1 (K), D55.1 (K), D62.1 (K), D65.1 (K), D70.1 (K), D74.1 (K), U1.5 (GPIO3)

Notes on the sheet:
Switch Matrix
Rotary Encoder

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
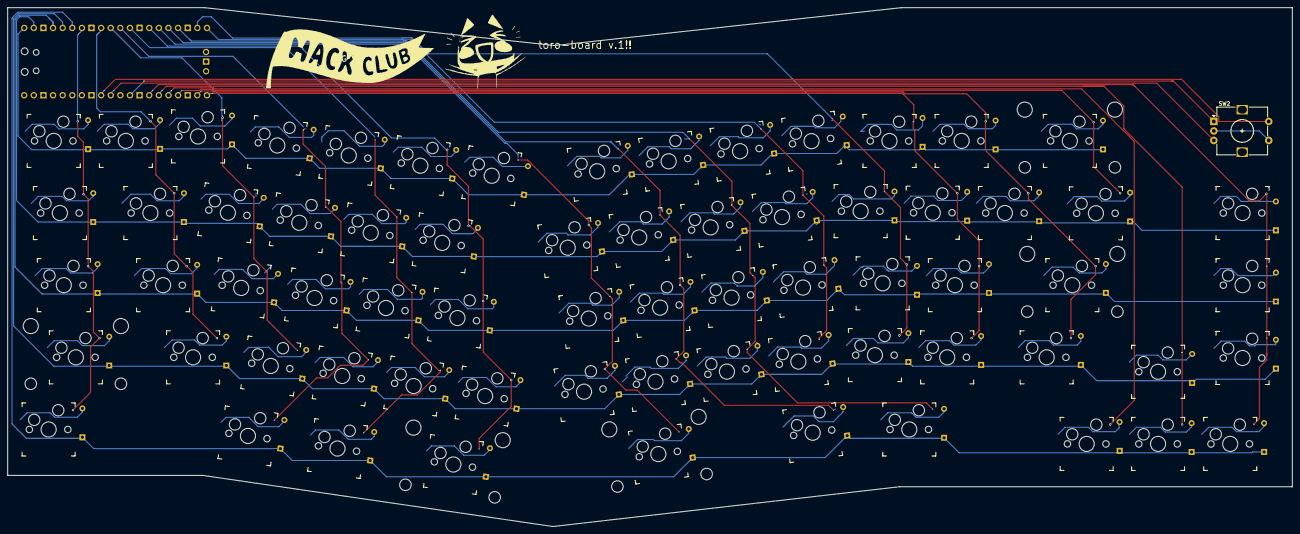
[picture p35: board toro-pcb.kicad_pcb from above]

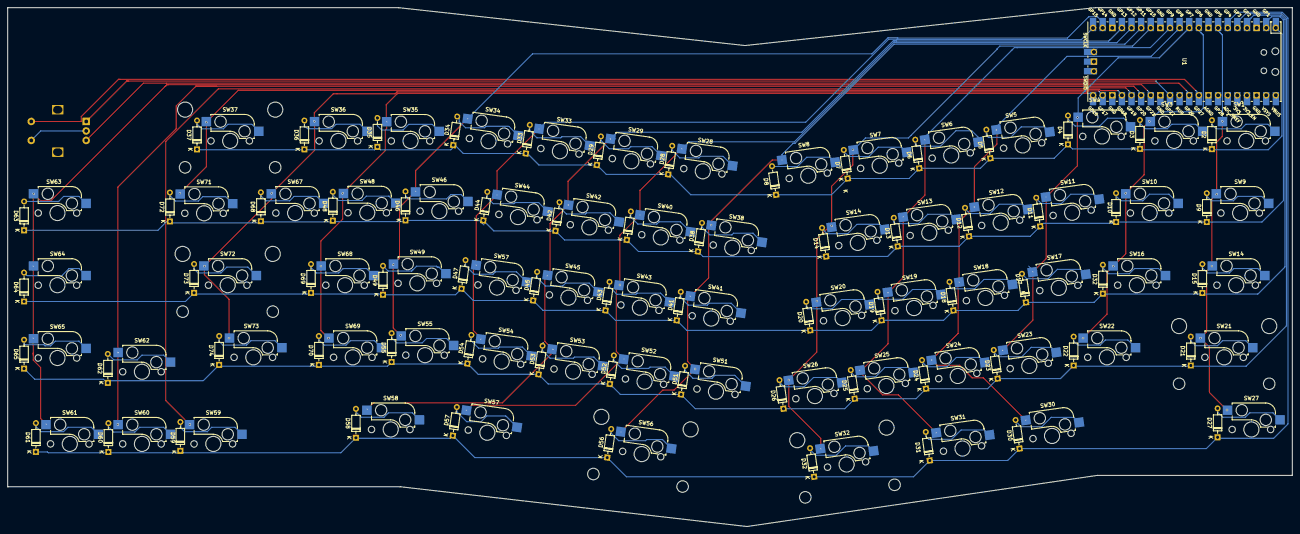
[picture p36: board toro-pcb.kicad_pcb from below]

Board: 2 copper layers, 339.2 x 137.0 mm, 138 parts (69 on the bottom side), 94 nets.

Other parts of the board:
D32#2: 1N4148; D_DO-35_SOD27_P7.62mm_Horizontal
SW14#2, SW57#2: Kailh_socket; Kailh_socket_MX

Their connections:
Col 9: SW57#2.1; also elsewhere on the board
unnamed 60: SW57#2.2; also elsewhere on the board

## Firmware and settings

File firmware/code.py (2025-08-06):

print("oh now u fuckin work")

import board

from kmk.kmk_keyboard import KMKKeyboard
from kmk.scanners.keypad import KeysScanner
from kmk.keys import KC
from kmk.modules.macros import Press, Release, Tap, Macros

keyboard = KMKKeyboard()

# macros = Macros()
# keyboard.modules.append(macros)

keyboard.col_pins = (board.GP5, board.GP6, board.GP7, board.GP8, board.GP9,
board.GP10, board.GP11, board.GP12, board.GP13, board.GP15,
board.GP14, board.GP16, board.GP17, board.GP18, board.GP19,
board.GP20, board.GP21)

keyboard.row_pins = (board.GP0, board.GP1, board.GP2, board.GP3, board.GP4)

keyboard.keymap = [
   [KC.ESC]
]

keyboard.keymap = [
    [
    KC.ESC, KC.N1, KC.N2, KC.N3, KC.N4, KC.N5, KC.N6, KC.N7, KC.N8, KC.N9, KC.N0, KC.MINS, KC.EQL, KC.BSPC,
    KC.TAB, KC.Q, KC.W, KC.E, KC.R, KC.T, KC.T, KC.Y, KC.U, KC.I, KC.O, KC.P, KC.LBRC, KC.RBRC, KC.BSLS, KC.DEL,
    KC.CAPS, KC.A, KC.S, KC.D, KC.F, KC.G, KC.H, KC.J, KC.K, KC.L, KC.SCLN, KC.QUOT, KC.ENT, KC.PGUP,
    KC.LSFT, KC.Z, KC.X, KC.C, KC.V, KC.B, KC.B, KC.N, KC.M, KC.COMM, KC.DOT, KC.SLASH, KC.RSFT, KC.UP, KC.PGDN,
    KC.LCTRL, KC.LGUI, KC.LALT, KC.SPACE, KC.SPACE, KC.A, KC.RCTRL, KC.LEFT, KC.DOWN, KC.RIGHT
    ]
]

# replace kc.a with kc.fn or wtv it is

if __name__ == '__main__':
    keyboard.go()
    
    

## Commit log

2025-06-05 switch layout
    [toro-pcb.kicad_pcb, toro-pcb.kicad_sch]
2025-06-05 #ididntsavemychanges. rotary encoder
    [toro-pcb.kicad_sch]
2025-06-05 led strip
    [toro-pcb.kicad_sch]
2025-06-06 set distance between centers to 19.05mm + add space and footprint for stabilizers
    [toro-pcb.kicad_pcb]
2025-06-06 big keys
    [toro-pcb.kicad_pcb]
2025-06-08 spacing christ all mighty
    [toro-pcb.kicad_pcb]
2025-06-08 vertically aligned right side 💀
    [toro-pcb.kicad_pcb]
2025-06-08 move leds to back
    [toro-pcb.kicad_pcb]
2025-06-08 i fucked up
    [toro-pcb.kicad_pcb]
2025-06-18 iiiiiuhhhuhhh rewiring
    [toro-pcb.kicad_pcb, toro-pcb.step]
2025-06-24 gasket mount spacing + readme
    [case-bottom - Part 1.step, case-top - Part 1.step, plate - Part 1 - Part 1.step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]
2025-06-25 submisiion requirements
    [BOM.csv]
2025-08-06 readme + kmk
    [nose2.cfg]
